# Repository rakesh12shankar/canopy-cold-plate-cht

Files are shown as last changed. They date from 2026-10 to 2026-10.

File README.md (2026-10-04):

# Canopy Cold Plate CHT — SolidWorks and ANSYS Fluent

A numerical reconstruction of a four-branch liquid cold plate, with analytical verification, mesh/material sensitivity studies and a controlled manifold-design extension.

**Status:** The refined equal-flow and equal-power comparisons are complete.

**Screening result:** the enlarged outlet manifold reduces hydraulic power 10.497% and maximum heated-base temperature by 1.075 K at 22.3 kg/h on the screening mesh. This adds approximately 9.6% coolant volume and reduces minimum cover from 2 to 1.5 mm. At equal flow, the refined outlet variant changes hydraulic power by -10.252% and maximum heated-base temperature by -1.0103 K. At the refined baseline hydraulic power, achieved flow is 23.2010 kg/h; heated-base mean/max change by -0.5921 / -1.4146 K. These are numerical comparisons with volume/cover tradeoffs, rather than experimentally validated hardware improvements.

## Read the project

- [Technical report](docs/technical_report.md): question, methods, results and limitations.
- [Results overview](docs/results_overview.md) and [controlled design study](docs/design_study.md).
- [Reproduction instructions](docs/reproducibility.md): dependencies, commands and evidence map.
- [Portfolio summary](docs/portfolio_summary.md).
- [Milestone status](docs/milestone_status.md).

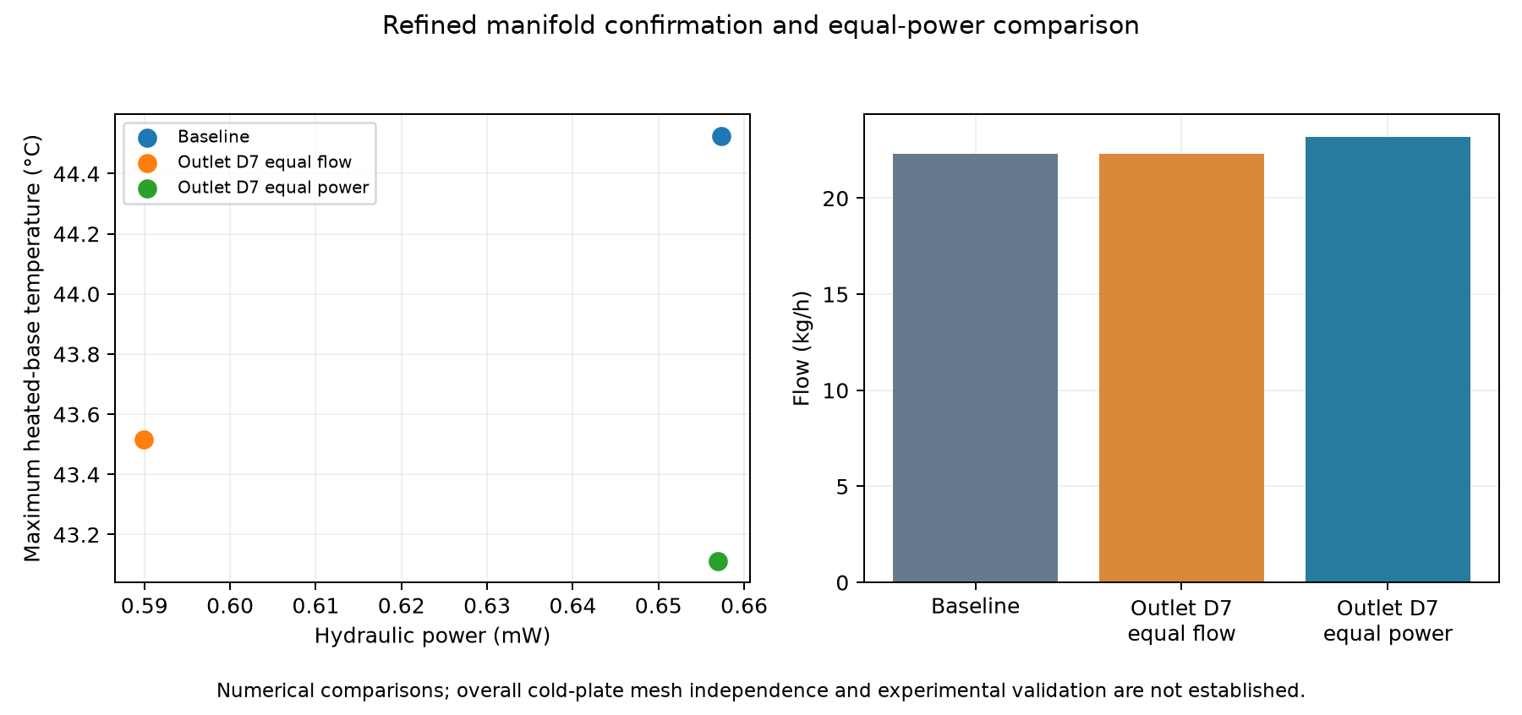
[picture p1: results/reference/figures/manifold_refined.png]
Refined manifold comparison


## What is implemented

- Connected SolidWorks solid/fluid CAD, including D7 inlet/outlet manifold variants and supplied Parasolid exports.
- Steady 3D laminar conjugate heat transfer with anisotropic solid conductivity and variable water viscosity/conductivity.
- Prior mesh/prism-layer, property and pressure–velocity algorithm sensitivities.
- Branch-flow and total-pressure diagnostics with section interpolation/closure checks.
- Three-mesh analytical heated-pipe verification: finest pressure/bulk-energy errors below 0.04%.
- Matched-flow geometry screening, refined confirmation and an equal-hydraulic-power continuation, with actual completion status documented above.

## Run

Compact-record analysis requires no Fluent or SolidWorks:

```sh
python -m pip install -r requirements.txt
python run_validation.py
python run_analysis.py
```

New calculations require licensed Fluent 2024 R1 on the recorded Windows workflow:

```sh
python -m pip install -r requirements-simulation.txt
python run_fluent.py --case baseline_screen
```

New outputs go to `.generated/`; archived evidence remains in `results/reference/`. SolidWorks is needed only to regenerate CAD. Consult the reproduction guide before executing the additional cases.

## Evidence and limits

The refined baseline differs from the paper: static pressure difference +11.98%, top mean +1.583 K, top maximum +1.283 K. Exact original CAD, water-property functions and temperature-averaging definitions remain unavailable. Numerical verification does not establish experimental validation. Overall cold-plate mesh independence and a cold-plate GCI are not claimed. The 200 W footprint load is 0.889 W/cm²; it is not a demonstrated high-heat-flux electronics cooling case.

## Source and repository scope

Guil-Pedrosa et al., International Journal of Thermal Sciences 214 (2025), 109918. [DOI](https://doi.org/10.1016/j.ijthermalsci.2025.109918). Water transport tables use [CoolProp](https://coolprop.org/fluid_properties/fluids/Water.html).

`config/` holds assumptions and recorded numerical settings; `data/` holds CAD and the parameter workbook; `docs/` holds methods and interpretation; `results/reference/` holds compact records and figures. Scripts live at the root, following the organization of the companion JT and microchannel repositories. Publisher PDFs, correspondence, temporary files, native solver binaries and license settings are excluded. No open-source license has yet been selected; public visibility does not itself grant general reuse rights.

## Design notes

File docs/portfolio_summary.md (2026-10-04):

# Portfolio summary

**Project:** canopy cold-plate conjugate heat-transfer study in SolidWorks, ANSYS Fluent and Python.

The refined equal-flow and equal-power comparisons are complete.

At equal flow, the refined outlet variant changes hydraulic power by -10.252% and maximum heated-base temperature by -1.0103 K. At the refined baseline hydraulic power, achieved flow is 23.2010 kg/h; heated-base mean/max change by -0.5921 / -1.4146 K. These are numerical comparisons with volume/cover tradeoffs, rather than experimentally validated hardware improvements.

Interview evidence: distinguish numerical verification from experimental validation; explain total versus static pressure loss; show the equal-flow mean/maximum tradeoff and increased coolant-volume/reduced-cover cost; discuss the remaining grid and source-geometry uncertainty. Do not claim exact paper reproduction, fully mesh-independent optimization, or demonstrated high-heat-flux hardware cooling.

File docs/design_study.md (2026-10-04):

# Controlled manifold study

Converged comparison records are available; inspect the checks before publication.

## Geometry and comparison conditions

Baseline: original four-branch canopy reconstruction. Inlet7 and Outlet7 enlarge only the selected internal trunk to D7 from y=10 to 125 mm. External D6 ports, branches, footprint and thickness are retained. The internal transition is a sharp step. Coolant volume rises about 9.6%; minimum nominal cover decreases from 2 to 1.5 mm. No mechanical qualification is included.

Same steady laminar CHT physics: 200 W bottom heat, inlet 23 °C, ambient top 24 °C, anisotropic solid conductivity, CoolProp viscosity/conductivity tables and fixed density/cp. Equal-flow cases use 22.3 kg/h. Hydraulic power is volumetric flow multiplied by mass-weighted total-pressure loss, excluding pump efficiency and external loop losses. Static pressure difference is reported separately.

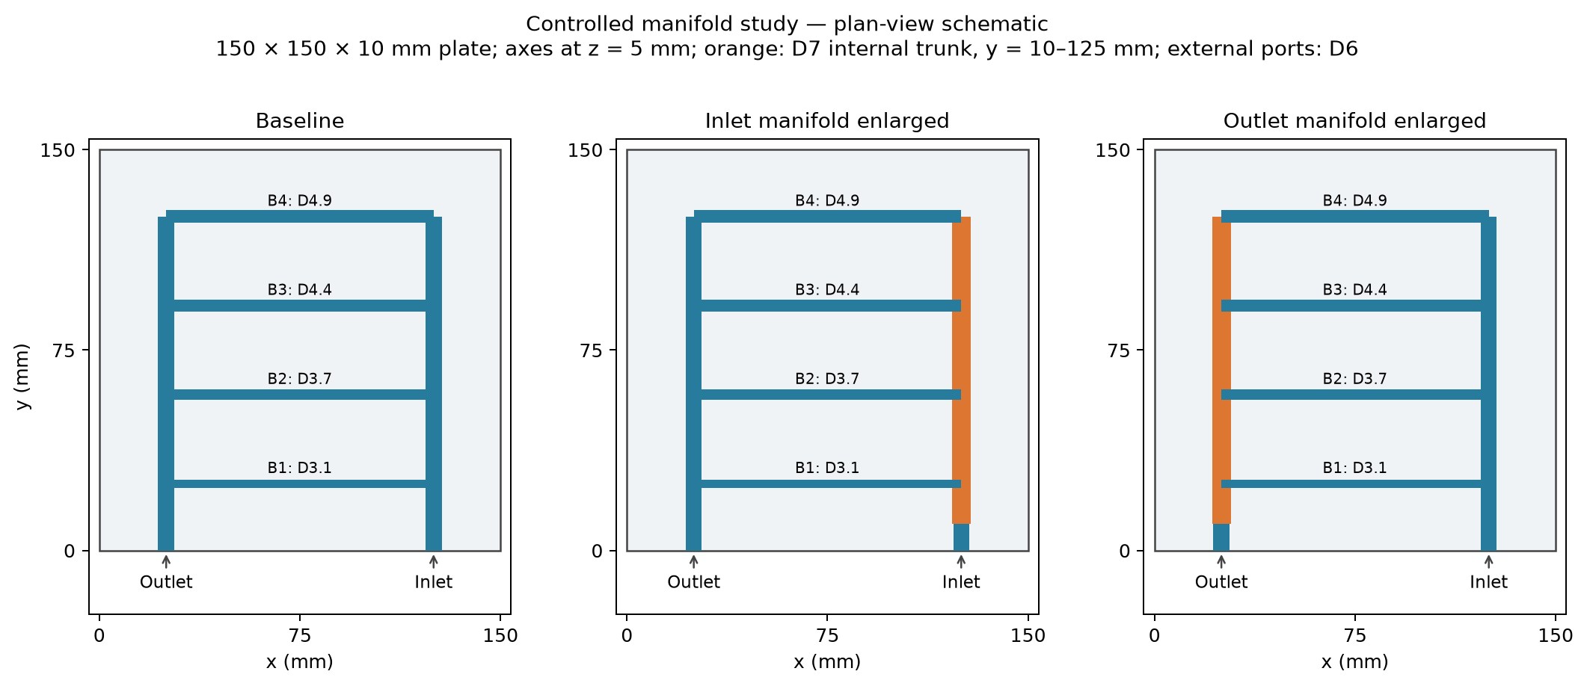
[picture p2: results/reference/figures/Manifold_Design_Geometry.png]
Geometry


## Completed results

| Case | Flow (kg/h) | Base mean (°C) | Base max (°C) | Mean R (K/W) | Static Δp (Pa) | Total loss (Pa) | Hydraulic power (mW) |

|---|---:|---:|---:|---:|---:|---:|---:|

| baseline_refined | 22.3000 | 39.6696 | 44.5263 | 0.083348 | 91.0363 | 105.8563 | 0.65734 |
| baseline_screen | 22.3000 | 39.9317 | 44.7160 | 0.084658 | 96.1371 | 107.9371 | 0.67026 |
| inlet7_screen | 22.3000 | 40.0431 | 44.5469 | 0.085216 | 85.7964 | 97.7776 | 0.60717 |
| outlet7_refined_equal_power | 23.2010 | 39.0775 | 43.1116 | 0.080388 | 84.8401 | 101.6880 | 0.65697 |
| outlet7_refined | 22.3000 | 39.4474 | 43.5160 | 0.082237 | 79.5138 | 95.0040 | 0.58995 |
| outlet7_screen | 22.3000 | 39.5828 | 43.6411 | 0.082914 | 83.7584 | 96.6067 | 0.59990 |

At matched refined-baseline hydraulic power, the variant changes heated-base mean temperature by -0.5921 K and maximum by -1.4146 K. Achieved flow is 23.2010 kg/h; power mismatch is -0.056%. These are numerical differences, not experimentally validated design improvements. Interpret their magnitude against the grid changes and geometry uncertainty below.

Selection criterion: Lowest hydraulic power among the two enlarged-manifold variants at equal flow. This tests whether reduced resistance can offset any equal-flow thermal penalty at equal power; it is not a global optimization.

## Verification and uncertainty

Every new listed case must meet flow residuals ≤1e-6, energy ≤1e-9, mass imbalance <0.01%, and heat imbalance <0.01%. Equal-flow cases also require heated-base mean/max ranges ≤0.0001 K and total-pressure-loss range ≤0.01% across three saved checkpoints. Screening uses the Coupled pressure–velocity algorithm and its native multigrid controls. Confirmatory SIMPLEC runs tighten active equation AMG termination criteria to 0.001; each saved controls JSON records the actual settings. Intermediate residual plateaus are not accepted as converged results. The equal-power routine adjusts flow, then freezes the inlet and reconverges; allowable final power mismatch is 0.5%. Raw residual and balance records are retained in `03_ANSYS/Design_Study`.

Screening uses curvature 18°, minimum 0.16 mm, maximum 1.2 mm and five prism layers. Confirmatory meshing uses curvature 9°, minimum 0.09 mm, maximum 1.2 mm and eight layers, matching the existing refined baseline. Curved-wall faceting causes CAD-to-mesh volume discrepancy: the screening baseline fluid volume is about 5% below CAD. Report each mesh's volume and quality records. The older constant-property study showed opposing prism-layer and surface-refinement effects; overall mesh independence or a cold-plate GCI is not established.

The refined baseline's base temperatures are extracted offline from saved boundary-face SV_T and polygon areas. Their top mean/max cross-check native Fluent reports within 0.001 K. Native saved port reports supply its hydraulic reference: 0.65733685 mW. New cases use native Fluent heated-base and mass-weighted total-pressure reports. Section diagnostics retain area and interior-flow interpolation checks.

The independent pipe case verifies elementary laminar pressure loss and bulk energy to within 0.04% on its finest mesh. It does not experimentally validate this CHT geometry. Original CAD detail and heated-water functions from the paper remain unavailable, and the baseline differs from the paper. The 200 W footprint heat flux is 0.889 W/cm², not a demonstrated high-heat-flux electronics condition.

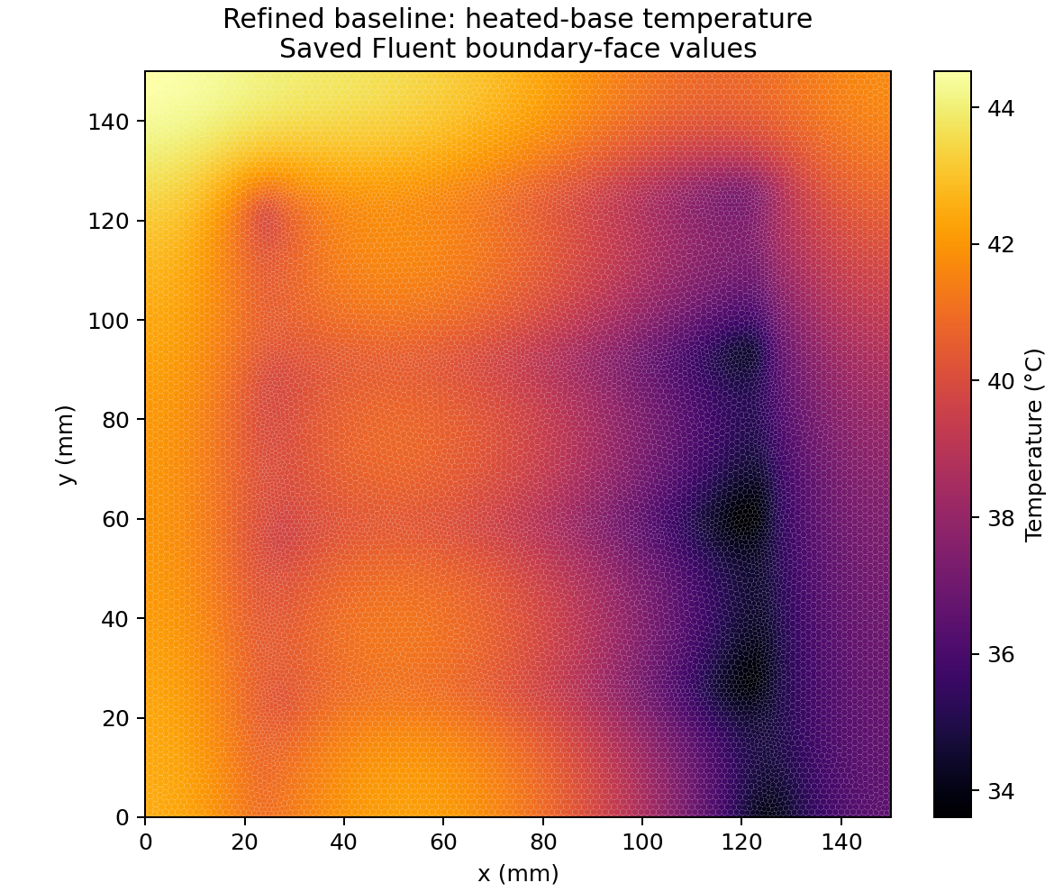
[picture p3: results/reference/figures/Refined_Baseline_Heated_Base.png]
Refined baseline heated base


## Reproduction

See `03_ANSYS/Design_Study/README.md` for the clean phase runner. `build_summary.py` regenerates this table only from converged saved records. Publication follows completion and review of the additions.

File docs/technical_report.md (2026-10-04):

# Canopy cold-plate conjugate heat-transfer study

## Research question

Can increasing one internal manifold diameter reduce resistance and heated-base temperature at fixed flow, and can the resistance benefit improve cooling at fixed hydraulic power? The independent numerical design study can proceed without the paper authors' exact CAD. Its literature comparison remains a reconstruction with explicitly missing inputs.

## Geometry and source separation

The reference is Guil-Pedrosa et al., International Journal of Thermal Sciences 214 (2025), 109918, [DOI](https://doi.org/10.1016/j.ijthermalsci.2025.109918). Table 2's Mesh 5 N4 case supplies rounded comparison values: 22.3 kg/h, inlet 23 °C, 200 W, ambient 24 °C; static pressure difference 81.3 Pa, top mean/max 37.7/42.9 °C and outlet 31.2 °C. The outlet averaging method is unspecified. These numbers do not prescribe all geometry and solver implementation details.

Reconstructed plate: 150 × 150 × 10 mm, D6 trunks at x=25/125 mm and z=5 mm. Four branches connect the trunks at y=25,58.333333,91.666667,125 mm, with diameters 3.1,3.7,4.4,4.9 mm. Sharp unions and flat terminal faces are retained. Exact original fillets, unrounded dimensions and material functions are unavailable.

Inlet7/Outlet7 enlarge the selected internal trunk to D7 over y=10–125 mm, retaining the D6 external port. Plate dimensions and branches are fixed. Coolant CAD volume rises approximately 9.6%; minimum nominal cover decreases from 2 to 1.5 mm. The sharp diameter step is a design assumption. No structural or manufacturing qualification is performed.

## Physical model

Steady 3D pressure-based laminar CHT, double precision, no gravity. Fluid/solid interfaces are coupled and conformal; walls are no-slip. Water viscosity and conductivity use CoolProp HEOS tables at atmospheric pressure over 15–60 °C. Density and cp remain fixed at 23 °C. Anisotropic solid k is 123.4/123.4/131 W/(m K), density 2590 kg/m³ and cp 915 J/(kg K).

The inlet has a parabolic circular profile calibrated to integrated 22.3 kg/h; inlet/backflow temperatures are 296.15 K. Outlet gauge pressure is zero. Bottom heat flux is 8888.8889 W/m², giving 200 W on 0.0225 m². Top ambient is 297.15 K with the source's piecewise natural-convection correlation and fixed 304 K air properties; remaining external surfaces are adiabatic. `config/physics.json` and `water_transport.json` contain executable inputs, including assumptions.

## Numerical verification and definitions

Screening: polyhedral mesh, 0.16–1.2 mm size, curvature 18°, five prism layers at growth 1.2. Confirmation: 0.09–1.2 mm, curvature 9°, eight layers, matching the prior refined baseline's settings. Discretization is second-order pressure/momentum/temperature, least-square gradients, with warped-face correction. Screening uses Coupled; confirmation uses SIMPLEC with tighter active-equation AMG termination. The earlier algorithm comparison showed negligible physical changes at checked converged conditions.

New cases require continuity/momentum residuals ≤1e-6, energy ≤1e-9, mass and heat imbalances <0.01%, and three saved checkpoints with base mean/max ranges ≤0.0001 K and total-pressure-loss range ≤0.01%. The equal-power procedure adjusts flow, freezes the inlet, then reconverges with these checks and ≤0.5% power mismatch. Saved checkpoints may be separated by fewer iterations when Fluent meets its stopping criteria.

Hydraulic power is `abs(mdot)/rho × (mass-weighted inlet total pressure − mass-weighted outlet total pressure)`. It excludes external loop losses and pump efficiency. Static pressure difference is a separate area-average metric. Heated-base resistance is `(base temperature − inlet temperature)/200 W`, using area mean or face maximum as labeled. The paper's top temperatures remain separate.

The analytical pipe case uses an axisymmetric R3 mm, L100 mm pipe, nominal mean U0.1 m/s, inlet 23 °C and wall heat flux 5000 W/m². Three meshes verify interior Poiseuille pressure loss and bulk energy, using each mesh's actual integrated flow. Finest errors are below 0.04%; the energy comparison neglects axial conduction while Fluent retains it. This does not experimentally validate the CHT plate.

## Findings and remaining uncertainty

The refined equal-flow and equal-power comparisons are complete.

The screening outlet enlargement reduces hydraulic power 10.497% and changes maximum base temperature -1.0749 K. At equal flow, the refined outlet variant changes hydraulic power by -10.252% and maximum heated-base temperature by -1.0103 K. At the refined baseline hydraulic power, achieved flow is 23.2010 kg/h; heated-base mean/max change by -0.5921 / -1.4146 K. These are numerical comparisons with volume/cover tradeoffs, rather than experimentally validated hardware improvements.

The outlet's equal-flow mean/max temperature benefit changes from -0.3489/-1.0749 K on screening meshes to -0.2222/-1.0103 K on refined meshes. Hydraulic-power reduction changes from 10.497% to 10.252%. The maximum-temperature and power benefits persist across these two resolutions; the smaller mean-temperature benefit is more sensitive. This comparison mixes mesh and algorithm changes, so it is sensitivity evidence, not a formal discretization-error estimate or confidence interval.

The refined reconstruction gives static Δp91.0363 Pa and top mean/max39.2829/44.1829 °C: +11.98% pressure, +1.583 K mean and +1.283 K maximum relative to the rounded source values. This discrepancy is preserved. No parameter fitting is used to claim source reproduction.

The prior layer/surface sensitivity changes oppose one another. No cold-plate GCI or overall mesh-independence claim is made. Screening curved-wall faceting lowers baseline mesh coolant volume roughly 5% versus CAD. Section diagnostics retain area, flow-closure and within-branch interpolation checks. Refined baseline midbranch Reynolds numbers are 507–618, consistent with laminar branches but insufficient to exclude junction recirculation or unsteadiness. Exact source CAD/material functions and raw data remain unavailable.

The load is 0.889 W/cm² over the footprint. This is a thermal-fluid portfolio study, not a demonstrated high-heat-flux compute-hardware cooling product.

## Reproducibility

See [commands and evidence map](reproducibility.md). Original geometry, numerical records and regenerated plots are included. Publisher PDFs, author correspondence, development transcripts, machine/license settings and full native solver binaries are excluded from this source package. Ansys licensing is required for new CFD runs. Source automation and documentation were prepared with AI assistance and checked against saved numerical evidence. No open-source reuse license is selected.

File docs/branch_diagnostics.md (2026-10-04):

# Finer-mesh water-property sensitivity and branch diagnostics

Both finer cases use the same 1,390,532-cell mesh, 22.3 kg/h inlet flow at 23°C, 200 W bottom heating, 24°C ambient and anisotropic aluminum conductivity. The sensitivity changes only water viscosity and thermal conductivity to temperature-dependent CoolProp HEOS functions at 101325 Pa. Density and heat capacity stay at the baseline 23°C values. The authors’ heated-model property functions remain unconfirmed.

| Case | Pressure drop (Pa) | Mean top (°C) | Maximum top (°C) | Bulk outlet (°C) |
|---|---:|---:|---:|---:|
| Finer, constant properties | 101.4506 | 40.0531 | 45.0491 | 30.6513 |
| Finer, variable viscosity/conductivity | 91.0363 | 39.2829 | 44.1829 | 30.6553 |
| Earlier fine mesh, variable viscosity/conductivity | 89.8891 | 39.5372 | 44.3993 | 30.6546 |
| Paper Table 2, Mesh 5 | 81.3 | 37.7 | 42.9 | 31.2* |

*The paper does not establish the outlet averaging definition; its value should not be treated as a confirmed bulk-temperature target.

On the finer mesh, variable viscosity/conductivity changes pressure by -10.4143 Pa (-10.27%), mean top by -0.7702 K and maximum top by -0.8661 K.
The finer transport case remains +11.98% from the paper pressure, +1.583 K from its mean top temperature and +1.283 K from its maximum.

## Branch flow distribution and sampled branch losses

B1–B4 correspond to y=25, 58.333333, 91.666667 and 125 mm; nominal diameters are 3.1, 3.7, 4.4 and 4.9 mm. Flow travels from x=125 mm toward x=25 mm. Flow fractions use the x=75 mm cuts. Pressure losses cover x=115 to x=35 mm: 80 mm of each branch, including possible developing flow, with junction regions and branch ends excluded.

| Properties | Branch | Flow (kg/h) | Inlet-flow share (%) | Static Δp, 80 mm (Pa) | Total Δp, 80 mm (Pa) |
|---|---|---:|---:|---:|---:|
| Constant | B1 | 3.6819 | 16.511 | 42.7167 | 42.0658 |
| Constant | B2 | 5.0484 | 22.639 | 21.6817 | 36.8447 |
| Constant | B3 | 6.4568 | 28.954 | 10.7949 | 26.8625 |
| Constant | B4 | 7.0556 | 31.639 | 15.2766 | 15.1134 |
| Variable μ/k | B1 | 3.7049 | 16.614 | 35.4203 | 35.7295 |
| Variable μ/k | B2 | 5.0365 | 22.585 | 16.2880 | 33.3589 |
| Variable μ/k | B3 | 6.4350 | 28.856 | 6.9889 | 24.2876 |
| Variable μ/k | B4 | 7.0690 | 31.699 | 12.7354 | 13.0485 |

## Approximate total-pressure loss budget

| Properties | Whole plate (Pa) | Inlet region (Pa) | Sampled branch portions (Pa) | Outlet region (Pa) | Branch portion (%) |
|---|---:|---:|---:|---:|---:|
| Constant | 114.9638 | 45.8987 | 27.9179 | 41.1473 | 24.28 |
| Variable μ/k | 105.8563 | 44.2729 | 24.6755 | 36.9079 | 23.31 |

Total pressure is mass-flow weighted and includes kinetic-energy effects. It differs from the area-averaged static pressure drop used for the paper comparison. Branch weights for the loss budget are normalized by their measured sum, making the regional split independent of pressure reference despite small cut-flow closure errors. The inlet region includes the inlet manifold, splitting junctions and branch portions before x=115 mm; the outlet region includes collecting junctions, the outlet manifold and branch portions after x=35 mm. This budget cannot isolate pure junction losses. Interior cut surfaces are interpolated, so the budget is diagnostic rather than an exact cell-face energy balance.

## Verification and interpretation limits

- constant: sum of branch flows at x=75 mm differs from inlet flow by -0.2570%; maximum within-branch variation across the five cuts is 0.3041%; maximum cut-area difference from nominal circular area is 1.800%.
- transport: sum of branch flows at x=75 mm differs from inlet flow by -0.2452%; maximum within-branch variation across the five cuts is 0.2901%; maximum cut-area difference from nominal circular area is 1.800%.

Transport solve: final iteration 1087, continuity 9.843e-07, energy 6.63e-11; mass imbalance 2.304e-06%, heat imbalance 5.493e-06%.

From the preceding saved checkpoint to the final solution, pressure changed by +0.000098 Pa, mean top by +0.000005 K and maximum top by +0.000000 K.

The fluid temperature range is 23.000 to 41.621°C, within the 15–60°C material tables. A recursive setup comparison confirms that only viscosity and thermal conductivity changed from the baseline.

Cut-area differences reveal the meshed cross-section rather than an exact analytic circle. Flow normalization preserves the imposed total inlet mass flow; it does not remove cross-section discretization effects. These diagnostics do not prove mesh independence or validate the geometry. No geometry or material values were fitted to the paper.

The user reports sending the author-data request. Original CAD, unrounded dimensions, heated-model property functions and report definitions are still awaited.

## Files and sources

- `Finer_Transport_Branch_Diagnostics.json`: compact numeric results and checks.
- `Finer_Transport_Sections.csv`: every sampled section, including manifold stations, pressures, flow and temperature; units appear in column names. Signed flow follows each surface normal, while branch tables use magnitudes.
- `Finer_Transport_Diagnostics.png`: branch-flow and pressure-loss comparison.
- `../03_ANSYS/Canopy_Finer_Transport_Study.wbpj`: Workbench comparison with diagnostic surfaces.
- `../03_ANSYS/Transport_Finer`: solver files, property tables and raw diagnostic records.

Paper: Guil-Pedrosa et al. (2025), https://doi.org/10.1016/j.ijthermalsci.2025.109918, Table 2. Surface integration definitions: https://ansyshelp.ansys.com/public/Views/Secured/corp/v242/en/flu_th/flu_th_sec_compute_surfint.html

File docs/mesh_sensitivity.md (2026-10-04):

# Follow-up mesh diagnostics

All cases use constant water properties at 23°C, 22.3 kg/h flow, 200 W bottom heating, 24°C ambient and the same nominal CAD. These mesh comparisons are separate from the earlier temperature-dependent-property sensitivity.

| Case | Fluid cells | Solid cells | Pressure drop (Pa) | Mean top (°C) | Maximum top (°C) |
|---|---:|---:|---:|---:|---:|
| Five layers, 12 degrees | 340,030 | 322,837 | 100.9957 | 40.2502 | 45.2041 |
| Eight layers, 12 degrees | 480,728 | 322,716 | 102.9814 | 40.2977 | 45.3216 |
| Eight layers, 9 degrees | 887,130 | 503,402 | 101.4506 | 40.0531 | 45.0491 |
| Paper Table 2, Mesh 5 | — | — | 81.3 | 37.7 | 42.9 |

## Changes between successive tests

- Five layers, 12 degrees → Eight layers, 12 degrees: pressure +1.9857 Pa (+1.966%); mean top +0.0475 K; maximum top +0.1175 K.
- Eight layers, 12 degrees → Eight layers, 9 degrees: pressure -1.5308 Pa (-1.487%); mean top -0.2446 K; maximum top -0.2725 K.

The layer and surface refinements change pressure in opposite directions. Close agreement between the first and last cases can therefore reflect partial cancellation, and does not demonstrate mesh independence.

The final constant-property case differs from the paper by +24.79% in pressure, +2.353 K in mean top temperature and +2.149 K in maximum top temperature.

## Conservation and convergence

| Case | Mass imbalance (%) | Heat imbalance (%) |
|---|---:|---:|
| Five layers, 12 degrees | 2.7925e-08 | 1.1007e-07 |
| Eight layers, 12 degrees | 1.3751e-06 | 4.2583e-06 |
| Eight layers, 9 degrees | 1.2867e-07 | 2.1439e-06 |

Baseline_simplec: final iteration 248, continuity 9.84e-07, maximum velocity residual 6.43e-10, energy 1.9e-12.

Prism: final iteration 400, continuity 9.83e-07, maximum velocity residual 2.66e-08, energy 3.94e-11.

Finer: final iteration 629, continuity 9.99e-07, maximum velocity residual 8.75e-09, energy 7.72e-12.

## Solver-algorithm control

The converged five-layer mesh was also continued with SIMPLEC. Relative to its original coupled solution, pressure changed by +0.000002 Pa (+0.000002%), mean top by -0.000000 K, and maximum top by +0.000000 K.
The table above uses this SIMPLEC baseline so all mesh comparisons use the same final coupling algorithm. The original coupled files remain unchanged.

## Scope and limitations

The first test increases the fluid smooth-transition layer count from five to eight at the same surface controls (12-degree curvature, 0.12/1.2 mm minimum/maximum). The second keeps eight layers and refines surface controls to 9 degrees and 0.09/1.2 mm. Prism growth rate stays 1.2. Smooth-transition first-cell heights and layer coverage depend on local geometry and meshing controls; these are controlled sensitivity tests, not a uniform three-grid family for formal GCI.

New meshes are initialized by separate fluid/solid interpolation from a converged case and then solved to the same residual and conservation criteria. Interpolation is only an initialization procedure.

The follow-up cases finish with SIMPLEC pressure–velocity coupling because the coupled solver caused heavy memory paging. Spatial discretization stays second order. Relaxation settings affect iterative convergence, not the specified physical steady-state model; the saved method/control JSON files record the final values.

The authors’ exact CAD, heated-model material functions and outlet averaging remain unresolved. The university repository API lists only the paper PDF in the ORIGINAL bundle, with separate license, text and thumbnail bundles; no CAD/model bundle was listed. Metadata snapshots are saved in `01_Reference`. A request draft is saved but has not been sent. The journal full-text endpoint returned HTTP 403, so publisher supplements remain unverified.

Source: Guil-Pedrosa et al. (2025), DOI https://doi.org/10.1016/j.ijthermalsci.2025.109918, Table 2. University record: https://vivo.uc3m.es/display/act576536.

## Saved artifacts

- `Followup_Mesh_Comparison.png`: comparison chart.
- `../03_ANSYS/Canopy_Convergence_Study.wbpj`: three-case Workbench study.
- `../03_ANSYS/Convergence/Canopy_T2_*`: converged case/data files and verification records.
- `../05_Notes/Author_Data_Request_Draft.md`: unsent request for missing reproduction data.

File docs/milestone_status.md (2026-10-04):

# Milestone status — 2026-10-04

Completed: reconstructed CAD and two controlled manifold variants; analytical pipe verification on three meshes; prior mesh, material and algorithm sensitivities; refined baseline heated-base and branch diagnostics; matched-flow screening of all three geometries with identical-physics audit.

The refined equal-flow and equal-power comparisons are complete.

Repository preparation: curated config/data/docs/results layout, portable relative inputs, compact-record validation, regenerated screening figure, and an isolated licensed CFD runner. The CLI and helper syntax are checked; the relocated full CFD runner has not yet been executed end to end. Existing numerical records were produced using the same numerical helpers in the original local project.

All six required CHT records and three analytical pipe records are present. Final convergence, balance, stability and branch diagnostics were reviewed; compact-record validation passes. The publication package excludes publisher PDFs, correspondence, license settings and development logs.

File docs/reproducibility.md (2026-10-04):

# Reproduction instructions

## Archived evidence versus new calculations

`results/reference/design_results.json` contains only completed, converged cases. Per-case records contain the raw report definitions, convergence checks, numerical controls, boundary classifications, mesh quality/layers and volumes. `physics_audit.json` checks that the screening cases use identical physics and methods. The older refined baseline uses saved native port reports and an explicitly labeled offline heated-base extraction cross-checked against its native top reports.

`run_validation.py` audits residuals, conservation, physical metric definitions and analytical pipe errors. `run_analysis.py` regenerates a CSV comparison and scientific figures into `.generated/analysis`, without changing the archived records. These are compact-record audits, not new solver runs or experimental validation.

```sh
python -m pip install -r requirements.txt
python run_validation.py
python run_analysis.py
python build_report.py
```

`build_report.py` rewrites the repository's generated narrative documentation and manifest from the archived completed records. Its incomplete-state handling must be retained if results are missing.

## New Fluent simulations

Recorded environment: Windows, Fluent 2024 R1, PyFluent 0.26.0, double precision, one process. Install `requirements-simulation.txt`, ensure Fluent is installed and licensed, and use one Fluent invocation at a time. The resource guard waits for other Fluent workers and sufficient Windows commit capacity without closing applications. Refined jobs can take hours on machines with limited physical RAM.

```sh
python -m pip install -r requirements-simulation.txt
python run_fluent.py --case baseline_screen
python run_fluent.py --case inlet7_screen
python run_fluent.py --case outlet7_screen
python run_fluent.py --case outlet7_refined
python run_fluent.py --case outlet7_refined --equal-power
```

Only the two candidate geometries are screened. The lowest equal-flow hydraulic-power variant is selected for refinement; the recorded winner is Outlet7. No global optimum is asserted. Supplied baseline-refined records supply the equal-power reference, 0.65733685 mW. New results remain in `.generated/fluent`; they do not overwrite `results/reference`.

Mesh generation reads the supplied two-body Parasolid CAD, shares topology, discovers the region labels dynamically, assigns plate/fluid regions and checks named boundary bounds. Fluid/solid volumes and total plate volume are checked before solving. Region identification depends on this two-region plate geometry and the larger exterior surface count of the solid. It is not a general-purpose arbitrary-CAD classifier.

The runtime helpers preserve the numerical workflow used in the local study. Relocated full-run validation is not yet complete. A saved generated case is retained on repeated invocation; deleting or moving generated outputs is a deliberate user action. No restart of a partially converged solve is currently exposed by the public CLI; inspect saved checkpoints before rerunning a failed calculation.

## CAD and pipe mesh

`data/cad/baseline`, `inlet7` and `outlet7` contain native SolidWorks and Parasolid fluid/solid/combined bodies. To regenerate, run the corresponding `build_*_geometry.ps1` with an explicit `-OutputDirectory` pointing inside `.generated/cad`. These scripts target SolidWorks 2019 COM interop/template locations. Adjust installation paths for a different SolidWorks installation. A SolidWorks session may become visible during CAD construction.

`build_pipe_mesh.py` contains the independently constructed axisymmetric Fluent ASCII mesh writer. The complete pipe setup, analytical equations and three-mesh records are documented in `docs/pipe_verification.md`. It is a separate elementary numerical check, not an electronics experiment.

With licensed Fluent and no concurrent Fluent worker, regenerate the independent check using `python run_pipe_verification.py`. Use `--mesh coarse` for a short single-mesh check. Outputs go to `.generated/pipe`. This runner uses the recorded pipe setup and freshly initialized solver; it does not read cold-plate results or fit properties to the reference errors.

## Publication exclusions

The source package includes project-owned CAD, scripts, derived numerical records, the parameter workbook, and original scientific figures. It excludes publisher PDF copies/full-text extracts, author-email drafts, machine/server/license settings, development transcripts, temporary workflow folders, and full native Fluent case/data binaries. Archived binaries remain in the original local study; regenerating them requires licensed Fluent and the documented inputs. No dataset gaps are filled with simulated or guessed measurements.

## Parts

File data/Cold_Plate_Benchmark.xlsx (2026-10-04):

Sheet: Benchmark Inputs
Canopy-to-canopy benchmark inputs
Guil-Pedrosa et al. (2025). Four-branch plate. Blank numeric cells require documented property choices.
Parameter | Numeric value | Unit | Evidence | Source location | Interpretation / action | Source URL
Number of branches | 4 | count | Reported / selected | p.3, Table 1 | Use the four-branch constructal design. | https://doi.org/10.1016/j.ijthermalsci.2025.109918
Solid material |  |  | Reported | p.4, Sec.3.1 | 3D-printed AlSi10Mg aluminum. | https://doi.org/10.1016/j.ijthermalsci.2025.109918
In-plane conductivity kx = ky | 123.4 | W/(m K) | Reported | p.4, Sec.3.1 | Align x and y with the plate plane. | https://doi.org/10.1016/j.ijthermalsci.2025.109918
Through-thickness conductivity kz | 131 | W/(m K) | Reported | p.4, Sec.3.1 | Align z with the 10 mm thickness. | https://doi.org/10.1016/j.ijthermalsci.2025.109918
Solid density | 2590 | kg/m^3 | Reported | p.4, Sec.3.1 | Material property for the aluminum plate. | https://doi.org/10.1016/j.ijthermalsci.2025.109918
Solid heat capacity | 915 | J/(kg K) | Reported | p.4, Sec.3.1 | Steady benchmark first; retain for later transient work. | https://doi.org/10.1016/j.ijthermalsci.2025.109918
Coolant |  |  | Reported | pp.4–5, Sec.3 | Water. Property law and values must be documented. | https://doi.org/10.1016/j.ijthermalsci.2025.109918
Inlet temperature | 23 | degC | Reported | p.4, Sec.3.1 | Apply to all three thermal cases. | https://doi.org/10.1016/j.ijthermalsci.2025.109918
Ambient temperature setpoint | 24 | degC | Reported | p.4, Sec.3.1 | Experimental mean is 24.1 degC (p.9). Record which value is used. | https://doi.org/10.1016/j.ijthermalsci.2025.109918
Bottom heater power | 200 | W | Reported | pp.4–5, Sec.3 | Uniform heat input over the entire square bottom. | https://doi.org/10.1016/j.ijthermalsci.2025.109918
Heated bottom area | 0.0225 | m^2 | Derived | p.3, Fig.1; p.5, Sec.3.2 | Full 150 mm square. Formula links to geometry. | https://doi.org/10.1016/j.ijthermalsci.2025.109918
Bottom heat flux | 8888.8889 | W/m^2 | Derived | p.5, Sec.3.2 | Power divided by heated area. | https://doi.org/10.1016/j.ijthermalsci.2025.109918
Bottom heat flux | 0.8889 | W/cm^2 | Derived | p.5, Sec.3.2 | This is a low-heat-flux benchmark. | https://doi.org/10.1016/j.ijthermalsci.2025.109918
External lateral walls |  |  | Reported | p.5, Sec.3.2 | Adiabatic. | https://doi.org/10.1016/j.ijthermalsci.2025.109918
Upper surface |  |  | Reported | p.5, Eq.11 | Natural convection to ambient using the piecewise Kitamura correlation. Do not make this surface adiabatic. | https://doi.org/10.1016/j.ijthermalsci.2025.109918
Flow model |  |  | Reported | p.5, Sec.3.2 | Steady, laminar, incompressible conjugate heat transfer. | https://doi.org/10.1016/j.ijthermalsci.2025.109918
Inlet velocity profile |  |  | Reported | p.5, Sec.3.2 | Fully developed circular-pipe profile. u(r)=2 Umean [1-(r/R)^2], Umean=mass flow/(rho pi R^2). | https://doi.org/10.1016/j.ijthermalsci.2025.109918
Outlet gauge pressure | 0 | Pa | Reference choice | p.5, Sec.3.2 | Pressure outlet. Zero is the Fluent gauge reference choice. | https://doi.org/10.1016/j.ijthermalsci.2025.109918
Fluid-solid interfaces |  |  | Reported | p.5, Sec.3.2 | No-slip and coupled temperature / heat-flux continuity. | https://doi.org/10.1016/j.ijthermalsci.2025.109918
Water density |  | kg/m^3 | Unresolved | p.5, Sec.3.2 | Select an authoritative property source and temperature treatment before solving. | https://doi.org/10.1016/j.ijthermalsci.2025.109918
Water dynamic viscosity |  | Pa s | Unresolved | p.5, Sec.3.2 | Use the same documented property model in all cases. | https://doi.org/10.1016/j.ijthermalsci.2025.109918
Water heat capacity |  | J/(kg K) | Unresolved | p.5, Sec.3.2 | Needed for energy balance and coolant temperature rise. | https://doi.org/10.1016/j.ijthermalsci.2025.109918
Water thermal conductivity |  | W/(m K) | Unresolved | p.5, Sec.3.2 | Do not copy a reference temperature from a different paper. | https://doi.org/10.1016/j.ijthermalsci.2025.109918
Experimental pressure-fit a | 1800000 | Pa s^2/kg^2 | Reported fit | p.8, Table 4; Eq.14 | Four-branch experimental fit. Includes test setup effects. | https://doi.org/10.1016/j.ijthermalsci.2025.109918
Experimental pressure-fit b | 8600 | Pa s/kg | Reported fit | p.8, Table 4; Eq.14 | Delta P = a (mass flow)^2 + b (mass flow), with mass flow in kg/s. | https://doi.org/10.1016/j.ijthermalsci.2025.109918
Hydraulic test lower flow | 4 | kg/h | Reported range | p.4, Sec.3.1 | Seven points in total; individual flow settings are not tabulated. | https://doi.org/10.1016/j.ijthermalsci.2025.109918
Hydraulic test upper flow | 27.8 | kg/h | Reported range | p.4, Sec.3.1 | Hydraulic tests are isothermal at 23 degC. | https://doi.org/10.1016/j.ijthermalsci.2025.109918
Reference simulation software |  |  | Reported | p.5, Sec.3.2 | COMSOL. Reproduce the physical model in Fluent; its numerical controls need independent verification. | https://doi.org/10.1016/j.ijthermalsci.2025.109918

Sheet: Geometry Checklist
Four-branch nominal geometry
Coordinates below are a reconstruction from Fig.1 and Table 1, in mm. Native CAD is not supplied.
Parameter | Numeric value | Unit | Evidence | Source location | Interpretation / action | Source URL
Plate side L | 150 | mm | Reported | p.3, Sec.2 | Square plate in x and y. | https://doi.org/10.1016/j.ijthermalsci.2025.109918
Plate thickness s | 10 | mm | Reported | p.3, Sec.2 | Plate extends z = 0 to s. | https://doi.org/10.1016/j.ijthermalsci.2025.109918
Edge offset H | 25 | mm | Reported | p.3, Fig.1; Sec.2 | Offsets to trunk axes and first / last branch axes. | https://doi.org/10.1016/j.ijthermalsci.2025.109918
Branch count N | 4 | count | Linked selection | p.3, Table 1 | Four-branch constructal configuration. | https://doi.org/10.1016/j.ijthermalsci.2025.109918
Trunk diameter DT | 6 | mm | Reported | p.3, Table 1 | Both inlet and outlet trunks. | https://doi.org/10.1016/j.ijthermalsci.2025.109918
Branch diameter D1 | 3.1 | mm | Reported | p.3, Table 1 | Nearest to the shared inlet / outlet face. | https://doi.org/10.1016/j.ijthermalsci.2025.109918
Branch diameter D2 | 3.7 | mm | Reported | p.3, Table 1 | Second branch. | https://doi.org/10.1016/j.ijthermalsci.2025.109918
Branch diameter D3 | 4.4 | mm | Reported | p.3, Table 1 | Third branch. | https://doi.org/10.1016/j.ijthermalsci.2025.109918
Branch diameter D4 | 4.9 | mm | Reported | p.3, Table 1 | Furthest from inlet / outlet. | https://doi.org/10.1016/j.ijthermalsci.2025.109918
Branch spacing S | 33.333 | mm | Derived | p.3, Eq.1 | S=(L-2H)/(N-1). | https://doi.org/10.1016/j.ijthermalsci.2025.109918
Channel center elevation z | 5 | mm | Derived | p.3, Sec.2 | All circular channel axes at mid-thickness. | https://doi.org/10.1016/j.ijthermalsci.2025.109918
Outlet trunk x | 25 | mm | Coordinate convention | p.3, Fig.1 | Left trunk. Inlet and outlet on y=0 face. | https://doi.org/10.1016/j.ijthermalsci.2025.109918
Inlet trunk x | 125 | mm | Coordinate convention | p.3, Fig.1 | Right trunk. Origin at lower corner of shared port face. | https://doi.org/10.1016/j.ijthermalsci.2025.109918
Branch 1 y | 25 | mm | Derived coordinate | p.3, Fig.1 | Branch runs between trunk axes in x. | https://doi.org/10.1016/j.ijthermalsci.2025.109918
Branch 2 y | 58.333 | mm | Derived coordinate | p.3, Eq.1 | Branch runs between trunk axes in x. | https://doi.org/10.1016/j.ijthermalsci.2025.109918
Branch 3 y | 91.667 | mm | Derived coordinate | p.3, Eq.1 | Branch runs between trunk axes in x. | https://doi.org/10.1016/j.ijthermalsci.2025.109918
Branch 4 y | 125 | mm | Derived coordinate | p.3, Eq.1 | Branch runs between trunk axes in x. | https://doi.org/10.1016/j.ijthermalsci.2025.109918
Branch centerline length | 100 | mm | Derived nominal | p.3, Eq.2 | L-2H. Actual union volume accounts for intersecting cylinders. | https://doi.org/10.1016/j.ijthermalsci.2025.109918
Trunk nominal centerline extent | 125 | mm | Derived nominal | p.3, Eq.2 | y=0 to L-H. Exact end-cap and junction details need confirmation. | https://doi.org/10.1016/j.ijthermalsci.2025.109918
Minimum trunk wall ligament | 2 | mm | Derived nominal | p.3, Fig.1; Table 1 | (s-DT)/2 above and below trunk. | https://doi.org/10.1016/j.ijthermalsci.2025.109918
Design fluid volume | 12.4 | cm^3 | Reported nominal | p.3, Eq.2 | Target used by the design study. | https://doi.org/10.1016/j.ijthermalsci.2025.109918
Eq.2 volume from rounded diameters | 12.305 | cm^3 | Derived nominal | p.3, Eq.2; Table 1 | Idealized cylinder sum. Do not force the CAD union volume to equal 12.4 cm^3. | https://doi.org/10.1016/j.ijthermalsci.2025.109918
Junction blending / end caps |  |  | Unresolved | p.3, Fig.1 | Use documented nominal intersecting cylinders initially. Do not represent guessed fillets as published dimensions. | https://doi.org/10.1016/j.ijthermalsci.2025.109918
Roughness and print tolerances |  |  | Unresolved | p.4, Sec.3.1 | As-built details are not fully specified. Separate sensitivity studies from nominal reproduction. | https://doi.org/10.1016/j.ijthermalsci.2025.109918
CAD construction |  |  | Implementation plan | p.3, Fig.1 | Build a 150 x 150 x 10 solid, create the connected channel volume, subtract it from the solid and retain the fluid body. | https://doi.org/10.1016/j.ijthermalsci.2025.109918

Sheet: Benchmark Cases
Thermal cases and numerical reference
Prescribe Table 5 mass flows and 200 W. Pumping-power labels identify experimental cases.
Case / metric | Mass flow (kg/h) | Mass flow (kg/s) | Pump label (mW) | Heat input (W) | Heat flux (W/m^2) | Exp. fit ΔP (Pa) | Evidence / interpretation | Source URL
T1 | 14.4 | 0.004000 | 0.25 | 200 | 8888.89 | 63.20 | Table 5, four branches. Fit pressure is a calculated experimental trend, not raw data. | https://doi.org/10.1016/j.ijthermalsci.2025.109918
T2 | 22.3 | 0.006194 | 0.75 | 200 | 8888.89 | 122.34 | Table 5, four branches. Main starting case for comparison with Table 2. | https://doi.org/10.1016/j.ijthermalsci.2025.109918
T3 | 27.2 | 0.007556 | 1.25 | 200 | 8888.89 | 167.73 | Table 5, four branches. Do not impose both mass flow and pumping power. | https://doi.org/10.1016/j.ijthermalsci.2025.109918
Pressure comparison |  |  |  |  |  |  | Eq.14 / Table 4 fit includes setup effects. Intrinsic simulated plate pressure is lower (Sec.4.2). | https://doi.org/10.1016/j.ijthermalsci.2025.109918
Numerical reference |  |  |  |  |  |  | Table 2: four branches, 22.3 kg/h. Values below are COMSOL results, not experimental observations. | https://doi.org/10.1016/j.ijthermalsci.2025.109918
Metric | Mesh 5 | Mesh 6 | Unit |  |  |  | Compare Fluent at matching flow, power, BCs and surface definitions. | https://doi.org/10.1016/j.ijthermalsci.2025.109918
Mesh elements | 3520000 | 4590000 | count |  |  |  | Mesh density reference only. Establish independent mesh convergence in Fluent. | https://doi.org/10.1016/j.ijthermalsci.2025.109918
Pressure drop | 81.3 | 81.5 | Pa |  |  |  | Table 2 numerical pressure drop. Keep separate from the experimental fit above. | https://doi.org/10.1016/j.ijthermalsci.2025.109918
Outlet temperature | 31.2 | 31.3 | degC |  |  |  | Table 2 numerical outlet temperature. Confirm the averaging definition before comparison. | https://doi.org/10.1016/j.ijthermalsci.2025.109918
Upper-surface mean temperature | 37.7 | 37.8 | degC |  |  |  | Table 2 numerical reference. Report mean over the upper surface. | https://doi.org/10.1016/j.ijthermalsci.2025.109918
Upper-surface maximum temperature | 42.9 | 42.8 | degC |  |  |  | Table 2 numerical reference. Do not substitute whole-solid maximum. | https://doi.org/10.1016/j.ijthermalsci.2025.109918
Experimental thermal data |  |  |  |  |  |  | Digitize the relevant four-branch curves in Figs.7–9 or request raw data. Not yet entered. | https://doi.org/10.1016/j.ijthermalsci.2025.109918

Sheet: Open Items
Remaining details and comparison limits
Resolve these items before claiming experimental validation. Nominal CAD construction can begin.
Topic | Missing detail / finding | Source location | Next action / interpretation | Source URL
Water properties | Exact property values and temperature dependence are not tabulated. | p.5, Sec.3.2 | Choose a documented authoritative water-property model. Fill density, viscosity, cp and conductivity before setting Reynolds number or solving. | https://doi.org/10.1016/j.ijthermalsci.2025.109918
Top natural convection | Upper surface uses a piecewise Kitamura correlation. Air properties and reference temperature need implementation. | p.5, Eq.11 | Use the paper’s width-based Rayleigh number and stated validity ranges. Implement temperature-dependent h or iterate a documented effective value. | https://doi.org/10.1016/j.ijthermalsci.2025.109918
Ambient choice | Room setpoint 24 degC; measured average 24.1 degC. | p.4, Sec.3.1; p.9 | Record the value used. Check whether this small difference matters to the thermal comparison. | https://doi.org/10.1016/j.ijthermalsci.2025.109918
Nominal CAD details | Junction blending, termination shape and as-built tolerances are incomplete. | p.3, Fig.1; p.4, Sec.3.1 | Start with the dimensioned nominal network. Document end caps and intersections; assess sensitivity or request CAD for an exact replica. | https://doi.org/10.1016/j.ijthermalsci.2025.109918
Inlet profile | Fully developed flow is specified. | p.5, Sec.3.2 | Use a normalized parabolic inlet velocity profile at the prescribed mass flow, or a verified development section. Keep pressure report planes consistent. | https://doi.org/10.1016/j.ijthermalsci.2025.109918
Pressure measurement planes | Experiments include connector / tap effects that the intrinsic model does not reproduce. | p.8, Sec.4.2 | Compare intrinsic CFD with Table 2 first. Quantitative experimental pressure validation requires matching the test-domain pressure planes. | https://doi.org/10.1016/j.ijthermalsci.2025.109918
Raw experimental data | Thermal curves and seven hydraulic test points are not fully tabulated. | Figs.5,7–9; p.15 data statement | Digitize selected curves with extraction uncertainty or request raw data. Do not label fit-generated values as measurements. | https://doi.org/10.1016/j.ijthermalsci.2025.109918
Numerical convergence | COMSOL element counts do not prescribe a Fluent mesh. | p.6, Table 2 | Run at least three systematically refined meshes and check pressure drop, mean/max upper temperature, outlet temperature and conservation. | https://doi.org/10.1016/j.ijthermalsci.2025.109918
Thermal output definitions | Outlet temperature averaging must match the reference. | p.6, Table 2 | Record area- and mass-flow-weighted outlet temperatures until the definition is resolved. Use upper-surface mean and maximum for plate metrics. | https://doi.org/10.1016/j.ijthermalsci.2025.109918
Heat loss and radiation | The stated model includes top natural convection and insulated sides. | p.5, Sec.3.2; p.9 | Reproduce stated BCs first. Do not invent contact resistance or radiation parameters to force agreement. | https://doi.org/10.1016/j.ijthermalsci.2025.109918
Scope of benchmark | 200 W over 150 x 150 mm is about 0.889 W/cm^2. | pp.3–5 | This checks the CHT methodology at modest heat flux. A high-heat-flux compute cold plate is a separate later design study. | https://doi.org/10.1016/j.ijthermalsci.2025.109918

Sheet: Pipe Verification
Heated-pipe numerical verification
Water, 23 °C inlet; radius 3 mm; length 100 mm; nominal mean velocity 0.1 m/s; wall heat flux 5,000 W/m².
Mesh | Cells | Actual mean U (m/s) | Analytical Δp (Pa) | CFD Δp (Pa) | Pressure error (%) | Analytical bulk rise (K) | CFD bulk rise (K) | Bulk-rise error (%) | Heat imbalance (%)
coarse | 2000 | 0.10013 | 4.97755 | 4.96205 | -0.31146 | 0.79799 | 0.79783 | -0.01963 | 0.00046
medium | 8000 | 0.10003 | 4.97289 | 4.96893 | -0.07974 | 0.79874 | 0.79851 | -0.02797 | 0.00102
fine | 32000 | 0.10001 | 4.97173 | 4.97074 | -0.01985 | 0.79892 | 0.79864 | -0.03482 | 0.00097
Pressure comparison uses the integrated flow on each mesh. Temperature error is nonmonotonic; no thermal convergence order is claimed.
This case checks elementary laminar flow and bulk energy. It does not experimentally validate the cold plate.
Methodological reference | https://ansyshelp.ansys.com/public/Views/Secured/corp/v242/en/fbu_vm/Hlp_VMFL002.html

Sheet: Manifold Study
Controlled manifold study
200 W bottom load; inlet 23 °C. Completed, converged results are listed below. Missing variant results remain pending.
Geometry | Inlet trunk (mm) | Outlet trunk (mm) | External ports (mm) | Minimum cover (mm) | Result state
Baseline | 6 | 6 | 6 | 2 | Screening converged
Inlet7 | 7 | 6 | 6 | 1.5 | Screening converged
Outlet7 | 6 | 7 | 6 | 1.5 | Screening converged
D7 trunk begins at y=10 mm and ends at y=125 mm. Each variant increases CAD coolant volume about 9.6%; sharp steps are retained.
Refined baseline metric | Value | Units | Evidence
Base mean temperature | 39.66963 | °C | Saved boundary-face data; top metrics cross-checked
Base maximum temperature | 44.52627 | °C | Saved boundary-face data
Inlet temperature | 23.00000 | °C | Specified boundary condition
Heat input | 200.00000 | W | Specified bottom load
Mean base thermal resistance | 0.08335 | K/W | (Base mean − inlet)/heat input
Maximum base thermal resistance | 0.10763 | K/W | (Base maximum − inlet)/heat input
Reference hydraulic power | 0.0006573 | W | mdot/rho × mass-weighted total-pressure loss
Complete matched-flow screening, refined confirmation and equal-power comparison before claiming a design improvement.
The paper comparison remains incompletely specified. Numerical verification and experimental validation are distinct.
Completed CFD comparison records
Case | Cells | Flow (kg/h) | Base mean (°C) | Base max (°C) | Static Δp (Pa) | Total loss (Pa) | Hydraulic power (mW)
baseline_refined | 1390532 | 22.3000 | 39.6696 | 44.5263 | 91.0363 | 105.8563 | 0.6573
baseline_screen | 335962 | 22.3000 | 39.9317 | 44.7160 | 96.1371 | 107.9371 | 0.6703
inlet7_screen | 333006 | 22.3000 | 40.0431 | 44.5469 | 85.7964 | 97.7776 | 0.6072
outlet7_refined_equal_power | 1364916 | 23.2010 | 39.0775 | 43.1116 | 84.8401 | 101.6880 | 0.6570
outlet7_refined | 1364916 | 22.3000 | 39.4474 | 43.5160 | 79.5138 | 95.0040 | 0.5899
outlet7_screen | 324300 | 22.3000 | 39.5828 | 43.6411 | 83.7584 | 96.6067 | 0.5999

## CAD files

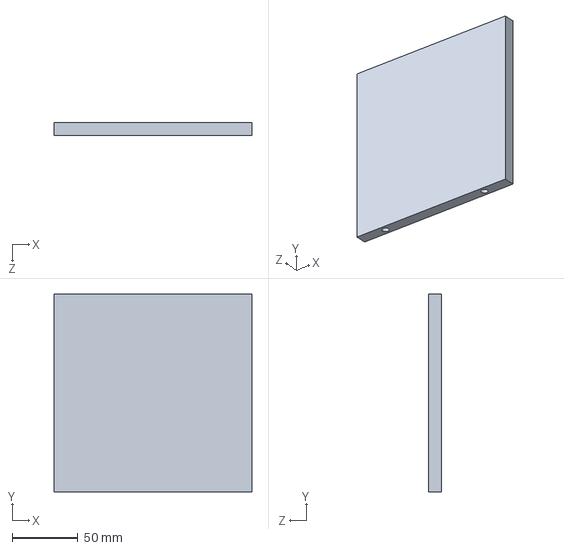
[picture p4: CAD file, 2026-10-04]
data/cad/baseline/Canopy_4Branch_Solid.SLDPRT
150.0 x 150.0 x 10.0 mm

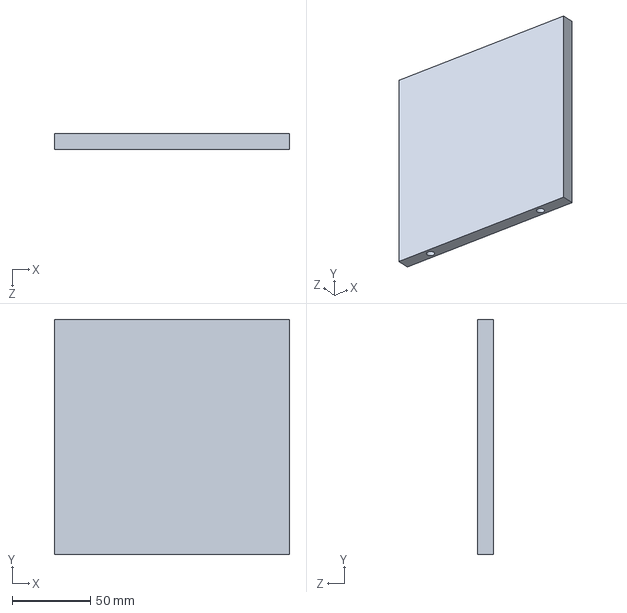
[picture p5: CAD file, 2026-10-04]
data/cad/inlet7/Canopy_Inlet7_Solid.SLDPRT
150.0 x 150.0 x 10.0 mm

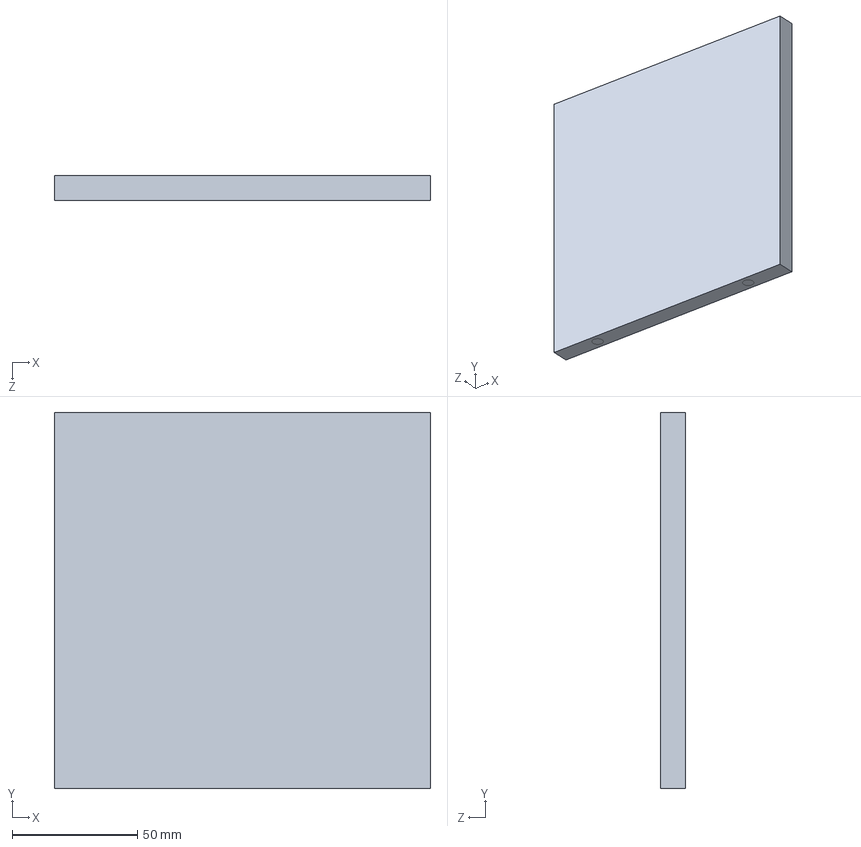
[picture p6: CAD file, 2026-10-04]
data/cad/outlet7/Canopy_Outlet7_CHT.SLDPRT
150.0 x 150.0 x 10.0 mm

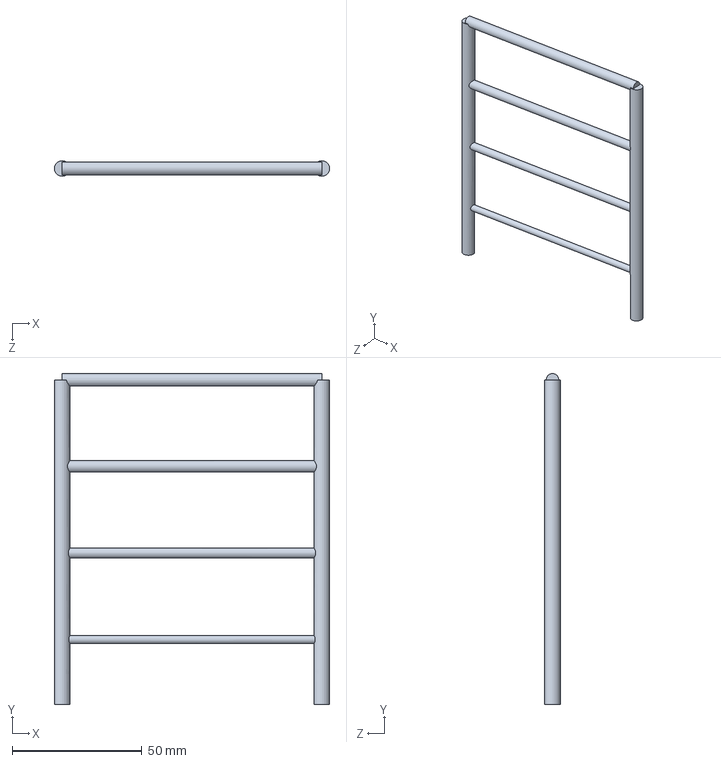
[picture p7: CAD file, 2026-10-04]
data/cad/baseline/Canopy_4Branch_Fluid.SLDPRT
106.0 x 127.5 x 6.00 mm

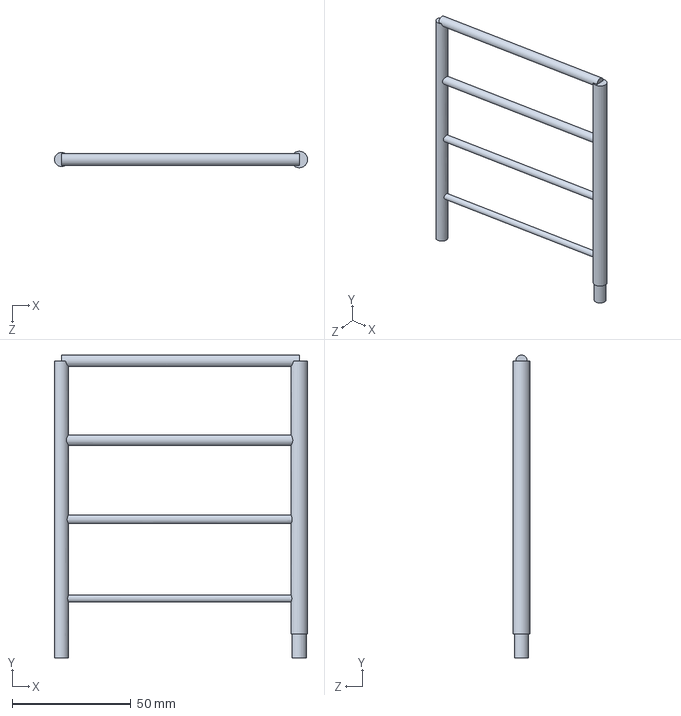
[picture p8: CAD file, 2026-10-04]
data/cad/inlet7/Canopy_Inlet7_Fluid.SLDPRT
106.5 x 127.5 x 7.00 mm

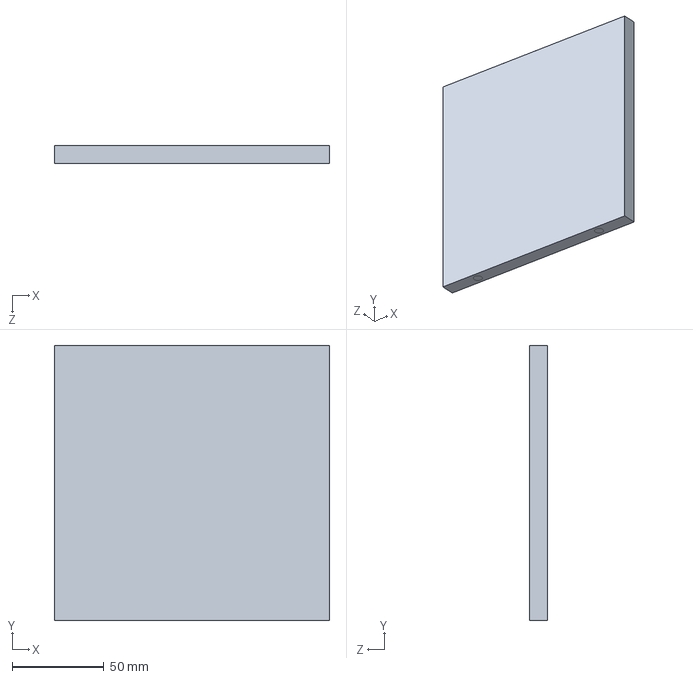
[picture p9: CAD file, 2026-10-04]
data/cad/baseline/Canopy_4Branch_CHT.SLDPRT
150.0 x 150.0 x 10.0 mm

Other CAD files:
data/cad/outlet7/Canopy_Outlet7_Fluid.SLDPRT
data/cad/inlet7/Canopy_Inlet7_CHT.SLDPRT
data/cad/outlet7/Canopy_Outlet7_Solid.SLDPRT
data/cad/baseline/Canopy_4Branch_CHT.x_t
data/cad/baseline/Canopy_4Branch_Fluid.x_t
data/cad/baseline/Canopy_4Branch_Solid.x_t
data/cad/inlet7/Canopy_Inlet7_CHT.x_t
data/cad/inlet7/Canopy_Inlet7_Fluid.x_t
data/cad/inlet7/Canopy_Inlet7_Solid.x_t
data/cad/outlet7/Canopy_Outlet7_CHT.x_t
data/cad/outlet7/Canopy_Outlet7_Fluid.x_t
data/cad/outlet7/Canopy_Outlet7_Solid.x_t

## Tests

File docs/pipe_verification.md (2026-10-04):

# Independent analytical pipe verification

## Purpose and scope

Verify elementary laminar-flow pressure loss and bulk energy balance independently of the canopy paper. This does not validate the cold plate experimentally or verify its anisotropic conjugate heat transfer.

## Reproducible setup

ANSYS Fluent 2024 R1, double precision, steady 2D axisymmetric, laminar, gravity off, energy enabled, second-order pressure/momentum/energy and pressure-based Coupled solution. Circular water pipe: radius 3 mm, length 100 mm, inlet 23 °C, nominal mean velocity 0.1 m/s, fully developed parabolic inlet, uniform wall heat flux 5,000 W/m², zero gauge-pressure outlet. Constant water properties at 23 °C match the project baseline. No viscous heating. Meshes are uniform axial/radial grids 100×20, 200×40 and 400×80.

Analytical pressure difference between x=20 and 80 mm: `Δp = 8 μ L_segment U_mean / R²`. Use the actual integrated flow-derived mean velocity for each mesh; inlet discretization produces nominal flow errors of 0.125%, 0.03125%, and 0.0078125%. Analytical wall heat is `Q = q_wall 2πRL = 9.424778 W`; bulk temperature rise is `Q / (mdot cp)`. This bulk estimate neglects axial conduction; Fluent retains conduction.

## Results

| Mesh | Cells | CFD interior Δp (Pa) | Pressure error (%) | CFD bulk rise (K) | Bulk-rise error (%) |
|---|---:|---:|---:|---:|---:|
| coarse | 2,000 | 4.962049 | -0.31146 | 0.797831 | -0.01963 |
| medium | 8,000 | 4.968926 | -0.07974 | 0.798512 | -0.02797 |
| fine | 32,000 | 4.970739 | -0.01985 | 0.798645 | -0.03482 |

The finest mesh gives Re=642.16. Pressure error decreases by approximately fourfold at each refinement. The observed order calculated from pressure resistance `Δp/U_mean` is 1.952. The thermal error is small but nonmonotonic; no thermal convergence order or thermal GCI is claimed. The residual thermal discrepancy has not been separated into axial-conduction, boundary-discretization and iterative contributions.

All cases meet flow residuals ≤1e-8, energy ≤1e-10, relative net mass flux <1e-6, and absolute net heat flux <1e-4 W. Finest heat imbalance is 0.000968% and mass imbalance is 3.075e-14%. These criteria and the agreement above support elementary numerical verification, not full physical validation.

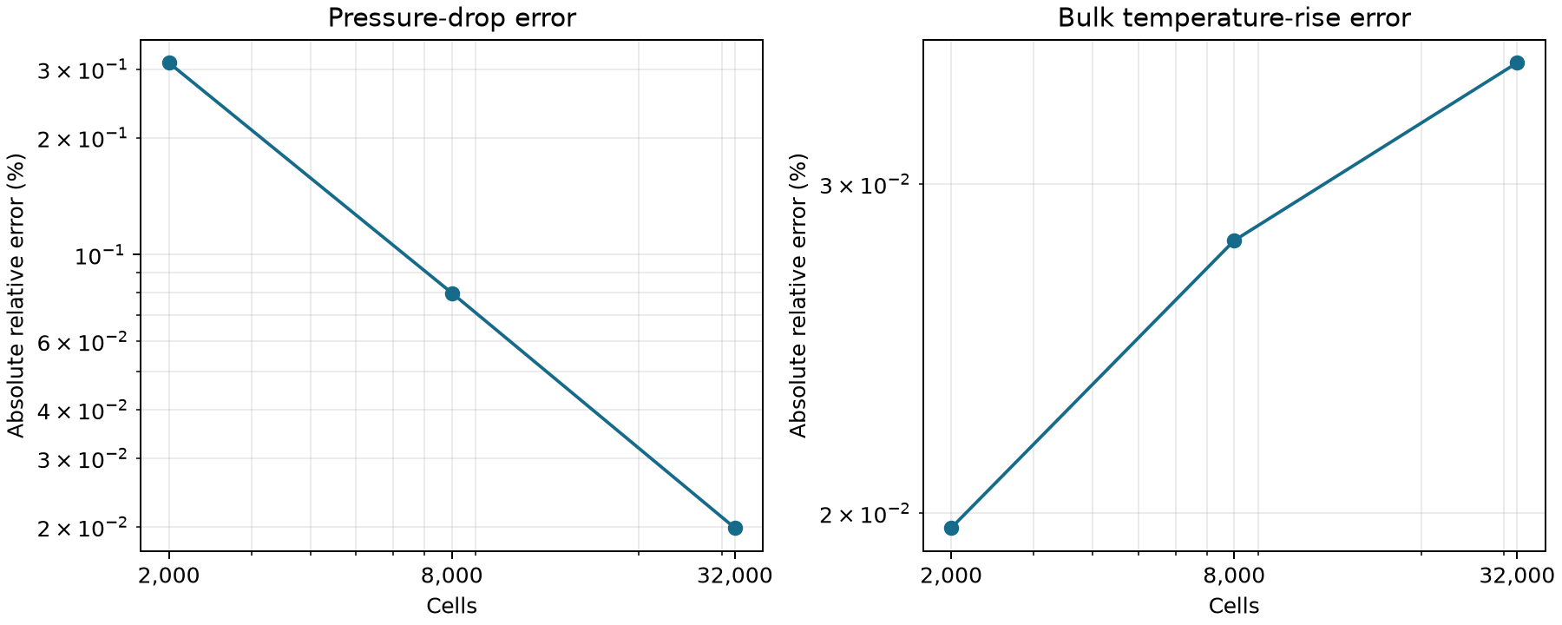
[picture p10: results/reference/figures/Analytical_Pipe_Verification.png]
Verification errors


## Files and sources

Scripts, meshes, converged case/data files, transcripts and raw JSON are in `03_ANSYS/Verification`. Run `pipe_mesh.py` and `solve_pipe.py` through the documented command driver; do not launch another solver over an active run. `build_report.py` rebuilds this report and figure from saved JSON.

- [ANSYS heated laminar pipe verification example](https://ansyshelp.ansys.com/public/Views/Secured/corp/v242/en/fbu_vm/Hlp_VMFL002.html): methodological precedent; our water case and metrics are independently specified.
- [NASA spatial convergence guidance](https://www.grc.nasa.gov/www/wind/valid/tutorial/spatconv.html): grid-refinement interpretation.

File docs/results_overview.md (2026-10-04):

# Results overview

The refined equal-flow and equal-power comparisons are complete.

The matched screening comparison selects the enlarged outlet manifold: hydraulic power falls 10.497% and maximum heated-base temperature changes -1.0749 K. The inlet enlargement has a different mean-temperature tradeoff. These are screening findings, not proof of mesh-independent optimization.

| Case | Cells | Flow (kg/h) | Base mean (°C) | Base max (°C) | Static Δp (Pa) | Total loss (Pa) | Hydraulic power (mW) |
|---|---:|---:|---:|---:|---:|---:|---:|
| baseline_refined | 1390532 | 22.3000 | 39.6696 | 44.5263 | 91.0363 | 105.8563 | 0.65734 |
| baseline_screen | 335962 | 22.3000 | 39.9317 | 44.7160 | 96.1371 | 107.9371 | 0.67026 |
| inlet7_screen | 333006 | 22.3000 | 40.0431 | 44.5469 | 85.7964 | 97.7776 | 0.60717 |
| outlet7_refined_equal_power | 1364916 | 23.2010 | 39.0775 | 43.1116 | 84.8401 | 101.6880 | 0.65697 |
| outlet7_refined | 1364916 | 22.3000 | 39.4474 | 43.5160 | 79.5138 | 95.0040 | 0.58995 |
| outlet7_screen | 324300 | 22.3000 | 39.5828 | 43.6411 | 83.7584 | 96.6067 | 0.59990 |

At equal flow, the refined outlet variant changes hydraulic power by -10.252% and maximum heated-base temperature by -1.0103 K. At the refined baseline hydraulic power, achieved flow is 23.2010 kg/h; heated-base mean/max change by -0.5921 / -1.4146 K. These are numerical comparisons with volume/cover tradeoffs, rather than experimentally validated hardware improvements.

The outlet's equal-flow mean/max temperature benefit changes from -0.3489/-1.0749 K on screening meshes to -0.2222/-1.0103 K on refined meshes. Hydraulic-power reduction changes from 10.497% to 10.252%. The maximum-temperature and power benefits persist across these two resolutions; the smaller mean-temperature benefit is more sensitive. This comparison mixes mesh and algorithm changes, so it is sensitivity evidence, not a formal discretization-error estimate or confidence interval.

Refined comparison

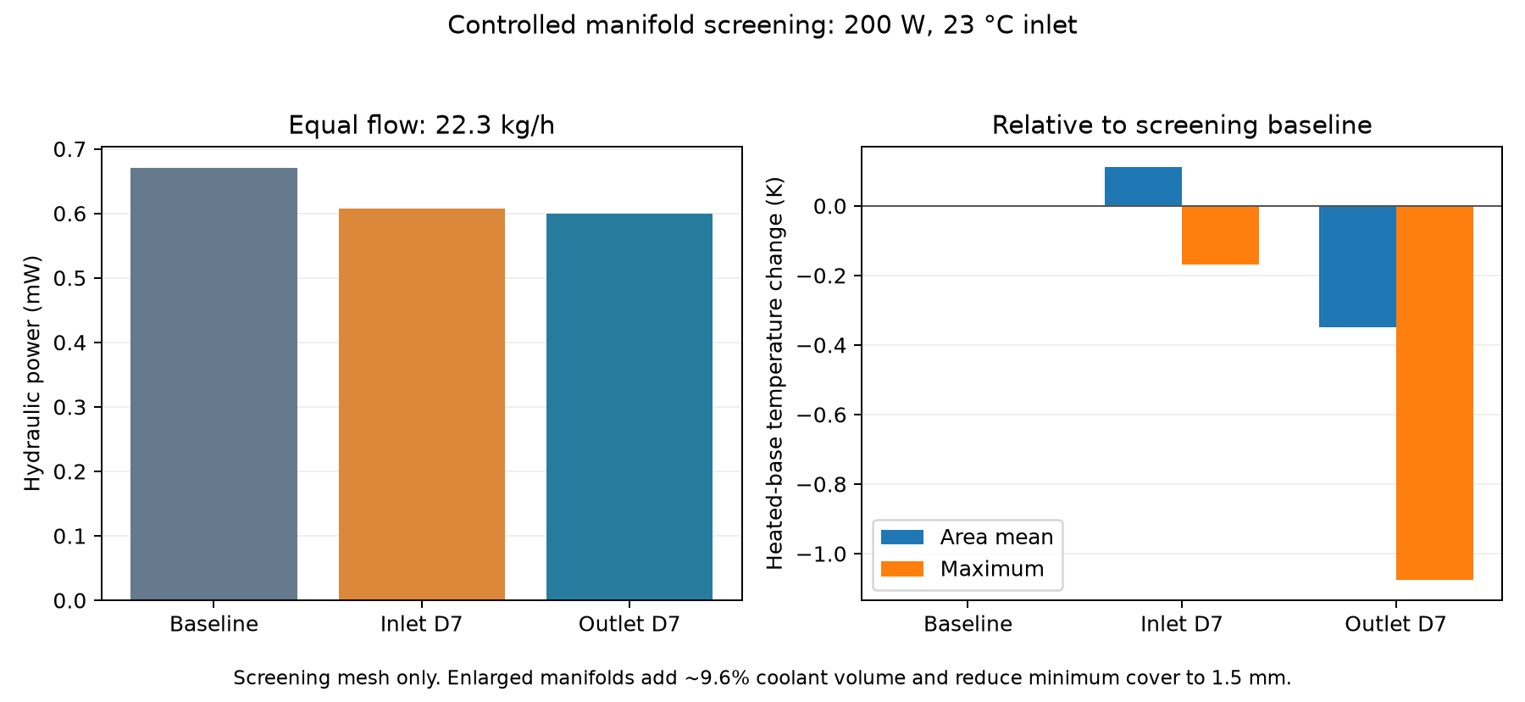
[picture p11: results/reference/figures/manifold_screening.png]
Screening comparison


The finest independent pipe check gives 0.01985% pressure-drop error and 0.03482% bulk-temperature-rise error. Its pressure resistance has observed order 1.952. Thermal errors are nonmonotonic; a thermal GCI is not claimed.

See [design study](design_study.md), [pipe verification](pipe_verification.md), [mesh sensitivity](mesh_sensitivity.md), and [branch diagnostics](branch_diagnostics.md). Compact solver records and the physics audit accompany these findings.

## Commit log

2026-10-04 Initialize verified cold-plate project publication
2026-10-04 Publish verified cold-plate CHT and manifold design study
    [Canopy_4Branch_CHT.SLDPRT, Canopy_4Branch_CHT.x_t, Canopy_4Branch_Fluid.SLDPRT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]
